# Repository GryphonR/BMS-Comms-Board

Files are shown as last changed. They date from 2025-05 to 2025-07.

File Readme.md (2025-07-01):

# eChook BMS Comunications Master Board
This project is heavily inspired by the [SimpBMS](https://github.com/Tom-evnut/SimpBMS) project by [Tom-evnut](https://github.com/Tom-evnut). The SimpBMS Hardware was never open-sourced, and has become obsolete post-COVID with the demise of the Teensy 3.x development boards.  
This board uses a Teensy 4.1 to mirror, then expand on the functionality of the original SimpBMS board.

While effort has been made to maintain some cross compatibility with the SimpBMS in connector choices and pinouts, this board is **not** a drop in replacement.

## License
This hardware design is released under a non-commercial open hardware licence, is provided **"as is"**, without warranty of any kind, express or implied. See the License.md file for details.

## Features

**ALL UNTESTED**

In addition to an expanded feature set over the SimpBMS, this board offers far more comprehensive circuit protection, most notably offering electrically isolated power and comms for the Battery Module connections, short circuit protection on all off board voltage feeds, so a harness issue does not take down the BMS, and 24v overvoltage protection on all digital and analogue inputs.

IO Overview:  
- 3 CAN Busses (All ESD protected, one Isolated for Battery Module comms).
    - Switchable Terminating Resistor for each bus.
- 2 UART, ESD protected and buffered.
    - One Isolated for Tesla Battery Module Comms.
    - One non-isolated, with selectable voltage levels.
- 1 RS-458/Modbus Interface
- 4 24v safe digital inputs
- 4 Monitored and Overcurrent protected 12v 5A High Side Drivers
- 4 5A Low Side Drivers
- 3 Short Circuit protected 12v outputs
- 4 Short Circuit Protected 5V outputs (One Isolated)
- 2 Analogue Inputs for Current Sensor signals, 24V safe.
- 1 I2C header for 0.91" OLED display.
- 1 SD card slot on the Teensy 4.1 to allow for logging with RTC timestamping.
- Ultra Bright Red error LED
- Warning Buzzer indicating BMS error or blown fuse (On, unless actively turned off by Teensy)

A little more detail:  
- Networks:
    - Electronically isolated communication busses for battery slave module communications.
        - Isolated 5V UART port for Tesla Module Communications (Teensy Serial2)
        - Isolated 600mA 5V supply 
        - Isolated CAN (Teensy CAN1) Connection for (most other) battery modules that communicate over CAN
    - Two non-isolated CAN busses, one exposed on the RJ-45 connector (CAN3), a second exposed on the J5 Auxillary Comms connector (CAN2)
    - One RS-485/MODBUS interface (Teensy Serial8)
    - RJ-45 connector with VICTRON compatible pin out as default, but 'Pick Your Own Pinout' pads on the bottom of the board to allow this to be modified to any application with a bit of soldering.
    - Serial output on J5 (Serial7). Voltage is selectable between 5V and 3.3v by solder jumper on rear of board.
- I/O
    - 4 High Impedence digital inputs, up to 24V.
    - 4 12V High Side Driver outputs, each with voltage, current and temperature monitoring, automatic over temperature, short circuit protection and error state reporting.
    - 4 PWM Capable Low Side Driver outputs with over current/short circuit protection, over temperature protecton. LOW Speed PWM only - testing needed, suspect <2KHz.
- Voltage Supply
    - 5V 500mA Isolated voltage supply for Tesla BMS Boards. Short circuit protected with red fault LED
    - 3 5V 500mA Voltage supplies on J2, J4 and J5, each short circuit protected with red fault LED
    - 3 12v Supplies on J4, Pins 10 and 11 sharing one short circuit protection ciruit, Pin 9 with it's own short circuit protection circuit.
- Warning System
    - Audible warning via a buzzer. This sounds if the onboard fuse blows, or if it is not actively being turned off by the Teensy.
    - Visual warning via 10mA Red LED. This is driven by the Teensy.
    - Heartbeat - Green LED located in cheesy silkscreen image of a heart will blink regularly if the system is healthy.

## Firmware
Due to the swap to a Teensy 4.1, expanded capabilities of the board, and a few pinout changes that go along with both of those, this board is not directly compatible with the SimpBMS code. There is an updated fork of the TeslaBMSV2 firmware adapted for this board here **TODO - link**.

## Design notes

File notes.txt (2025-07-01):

[x] Mosfet drivers - more than 330 gate R

[x] Mosfet - default ON

[x] 5V prot out - 400w TVS?

[x] UART Buffer - voltage switch on wrong input

[ ] advanced output v prot - mosfet right way around?

[x] Terminating Resistors - ensure 1/2W rating.

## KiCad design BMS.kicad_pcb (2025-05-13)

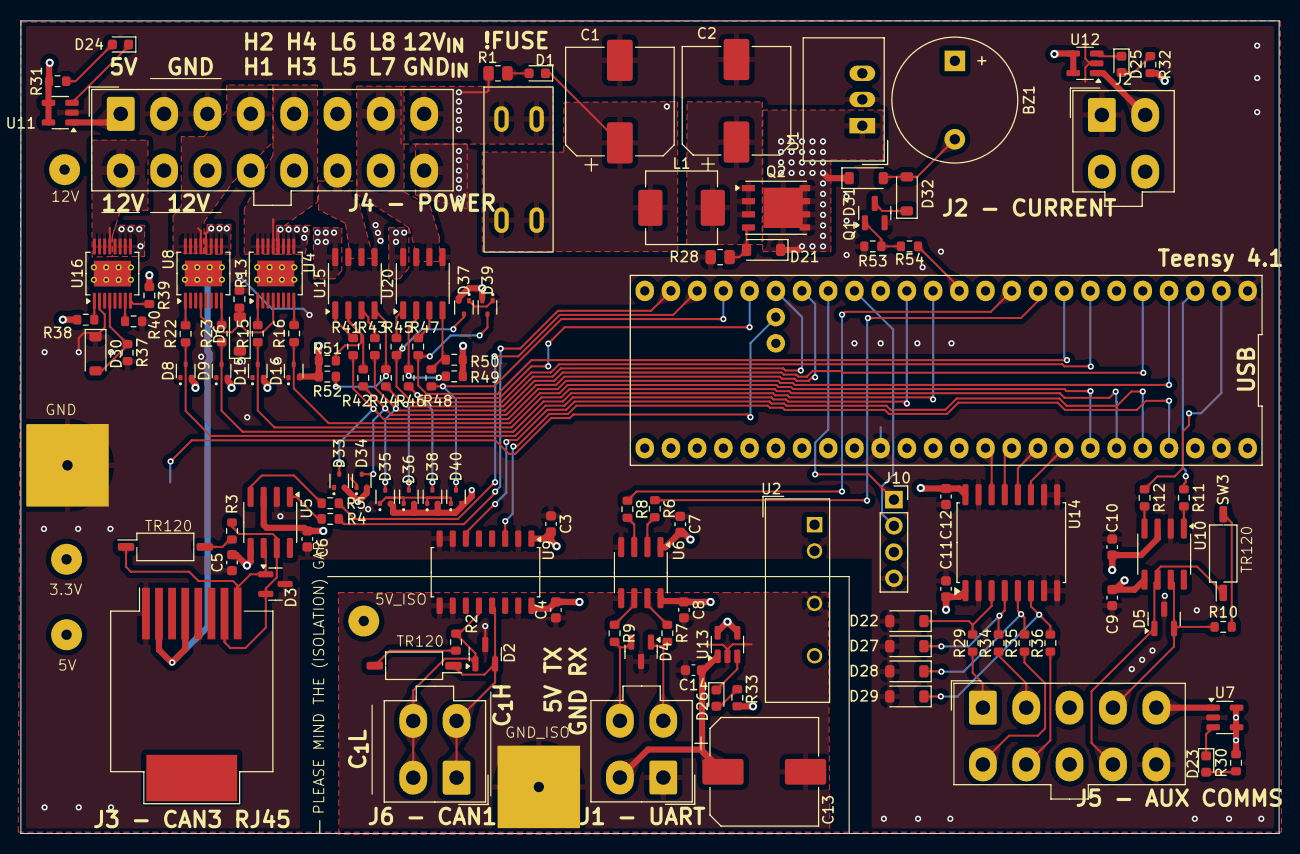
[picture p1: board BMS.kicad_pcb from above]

Board: 4 copper layers, 121.9 x 78.7 mm, 127 parts (1 on the bottom side), 108 nets.

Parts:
BT1: Battery_Cell; BatteryHolder_Keystone_1060_1x2032
BZ1: Buzzer; Buzzer_12x9.5RM7.6
C1, C2, C13: 470uF; CP_Elec_10x10
C3, C4, C5, C6, C7, C8, C9, C10, C11, C12, C14: 1uF; C_0603_1608Metric
D1: LED; LED_0603_1608Metric
D2, D3, D4, D5: PESD1CAN; SOT-23
D6, D30, D31, D32: D; D_SOD-123
D8, D9, D15, D16, D33, D34, D35, D36, D37, D38, D39, D40: BAT54S; SOT-523
D21: 10V; D_SOD-123
D22, D27, D28, D29: 4.7V Zener 500mW; D_SOD-123
D23, D24, D25, D26: LED_RED; LED_0603_1608Metric
F1: Mini Blade Fuse (10A); XFCN XF-508P-B-B
J1, J2, J6: Conn_02x02_Counter_Clockwise; Molex_Mini-Fit_Jr_5566-04A_2x02_P4.20mm_Vertical
J3: RJ45; RJ45_Molex_0855135013_Vertical
J4: Conn_02x08_Top_Bottom; Molex_Mini-Fit_Jr_5566-16A_2x08_P4.20mm_Vertical
J5: Conn_02x05_Top_Bottom; Molex_Mini-Fit_Jr_5566-10A_2x05_P4.20mm_Vertical
J10: OLED; PinSocket_1x04_P2.54mm_Vertical
L1: 1.5uH; L_Changjiang_FXL0618
Q1: BSS138LT1G; SOT-23
Q2: HSBA100P03; PowerPAK_SO-8_Single
R1, R28: 10k; R_0805_2012Metric
R2, R3, R10: 120; R_0603_1608Metric
R4, R5, R6, R7, R8, R9, R11, R12: 330R; R_0603_1608Metric
R13, R29, R34, R35, R36, R37, R53: 4.7k; R_0603_1608Metric
R15, R16, R22, R23, R38, R39: 15k; R_0603_1608Metric
R30, R31, R32, R33: 3.3k; R_0603_1608Metric
R40, R41, R42, R43, R44, R45, R46, R47, R48: 1k; R_0603_1608Metric
R49, R50, R51, R52: 47k; R_0603_1608Metric
R54: 330; R_0603_1608Metric
SW1, SW2, SW3: SW_DIP_x01; SW_DIP_SPSTx01_Slide_Copal_CHS-01B_W7.62mm_P1.27mm
TP1, TP4: TestPoint; Clip_TP
TP2, TP3, TP5, TP6: TestPoint; STD_TP
U1: K7805M-1000R3; Converter_DCDC_TRACO_TSR-1_THT
U2: B0505S-3WR2; Converter_DCDC_TRACO_TBA1-xxxxE_Single_THT
U3: Teensy4.1; Teensy_4.1_RTC
U4, U8, U16: VND7050AJTR; PowerSSO-16-1EP_3.9x4.9mm_P0.5mm_EP2.5x3.61mm_ThermalVias
U5, U10: TJA1051T/3/1J; SOIC-8_3.9x4.9mm_P1.27mm
U6: ISO7331C; SOIC-8_3.9x4.9mm_P1.27mm
U7, U11, U12, U13: TPS2051CDBV; SOT-23-5
U9: ISO1050DWR; SOP-16_4.55x10.3mm_P1.27mm
U14: CA-IS3740; SOIC-16W_7.5x10.3mm_P1.27mm
U15, U20: VNLD5090TR-E; SO-8_3.9x4.9mm_P1.27mm

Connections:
+3.3V: C3.2, C5.2, C7.2, C9.2, C12.2, D8.2 (K), D9.2 (K), D15.2 (K), D16.2 (K), D33.2 (K), D34.2 (K), D35.2 (K), D36.2 (K), D37.2 (K), D38.2 (K), D39.2 (K), D40.2 (K), J10.3, R49.2, R50.2, R51.2, R52.2, TP6.1, U3.15 (3V3), U3.46 (3V3), U3.50 (3.3V), U5.5 (Vref), U6.1 (VCC1), U9.1 (VCC1), U10.5 (Vref), U14.16 (VDD_{B})
+5V: C6.2, C10.2, C11.1, R30.2, R31.2, R32.2, R38.1, R39.1, TP5.1, U1.3 (Vout), U2.1 (+Vin), U3.48 (VIN), U5.3 (VDD), U7.4 (EN), U7.5 (IN), U10.3 (VDD), U11.4 (EN), U11.5 (IN), U12.4 (EN), U12.5 (IN), U14.1 (VDD_{A})
+5V_ISO: C4.2, C8.2, R33.2, TP3.1, U2.6 (+Vout), U6.8 (VCC2), U9.16 (VCC2), U13.4 (EN), U13.5 (IN)
+12V: D21.1 (K), D31.1 (K), J3.2, J3.4, Q2.5 (D), TP2.1, U1.1 (Vin), U4.17 (V_{cc}), U8.17 (V_{cc}), U16.17 (V_{cc})
/12V_INPUT: BZ1.1 (+), F1.1, J4.8, R1.2
/12V_Out_Bank1: J4.9, U16.13 (Output_0), U16.14 (Output_0), U16.15 (Output_0), U16.16 (Output_0)
/12V_Out_Bank2: J4.10, J4.11, U16.9 (Output_1), U16.10 (Output_1), U16.11 (Output_1), U16.12 (Output_1)
/12V_Output_Protection/Driver_Gnd: D30.2 (A), R37.1, U16.4 (GND)
/Buzzer_-ve: D32.1 (K), Q1.3 (D)
/Buzzer_Logic: R54.2, U3.12 (10_CS_MQSR)
/CAN1_HIGH_ISO: D2.2 (A2), J6.1, J6.3, SW1.1, U9.13 (CANH)
/CAN1_LOW_ISO: D2.1 (A1), J6.2, J6.4, R2.1, U9.12 (CANL)
/CAN1_RX: U3.45 (23_A9_CRX1_MCLK1), U9.3 (RXD)
/CAN1_TX: U3.44 (22_A8_CTX1), U9.6 (TXD)
/CAN2_HIGH: D5.2 (A2), J5.4, R10.1, U10.7 (CANH)
/CAN2_LOW: D5.1 (A1), J5.9, SW3.1, U10.6 (CANL)
/CAN2_RX: R12.1, U3.2 (0_RX1_CRX2_CS1)
/CAN2_TX: R11.1, U3.3 (1_TX1_CTX2_MISO1)
/CAN3_HIGH: D3.2 (A2), J3.7, R3.1, U5.7 (CANH)
/CAN3_LOW: D3.1 (A1), J3.8, SW2.1, U5.6 (CANL)
/CAN3_RX: R5.1, U3.22 (30_CRX3)
/CAN3_TX: R4.1, U3.23 (31_CTX3)
/High Side Drivers/Driver_Gnd: D6.2 (A), R13.1, U4.4 (GND), U8.4 (GND)
/In_1: J5.1, R29.1
/In_2: J5.2, R34.1
/In_3: J5.6, R35.1
/In_4: J5.7, R36.1
/Logic_IN_1: U3.38 (16_A2_RX4_SCL1), U14.14 (Out_{1})
/Logic_IN_2: U3.39 (17_A3_TX4_SDA1), U14.13 (Out_{2})
/Logic_IN_3: U3.40 (18_A4_SDA), U14.12 (Out_{3})
/Logic_IN_4: U3.41 (19_A5_SCL), U14.11 (Out_{4})
/OUT1_HSD_LOGIC: D9.3 (COM), R23.1, U3.13 (11_MOSI_CTX1)
/OUT1_HSD_PWR: J4.12, U8.9 (Output_1), U8.10 (Output_1), U8.11 (Output_1), U8.12 (Output_1)
/OUT2_HSD_LOGIC: D8.3 (COM), R22.1, U3.14 (12_MISO_MQSL)
/OUT2_HSD_PWR: J4.4, U8.13 (Output_0), U8.14 (Output_0), U8.15 (Output_0), U8.16 (Output_0)
/OUT3_HSD_LOGIC: D16.3 (COM), R16.1, U3.42 (20_A6_TX5_LRCLK1)
/OUT3_HSD_PWR: J4.13, U4.9 (Output_1), U4.10 (Output_1), U4.11 (Output_1), U4.12 (Output_1)
/OUT4_HSD_LOGIC: D15.3 (COM), R15.1, U3.43 (21_A7_RX5_BCLK1)
/OUT4_HSD_PWR: J4.5, U4.13 (Output_0), U4.14 (Output_0), U4.15 (Output_0), U4.16 (Output_0)
/OUT5_LSD_LOGIC: D33.3 (COM), R41.1, U3.4 (2_OUT2)
/OUT5_LSD_PWR: J4.14, U15.6 (Drain_{2})
/OUT5_LSD_Status: D34.3 (COM), R42.1, U3.18 (26_A12_MOSI1)
/OUT6_LSD_LOGIC: D35.3 (COM), R43.1, U3.5 (3_LRCLK2)
/OUT6_LSD_PWR: J4.6, U15.8 (Drain_{1})
/OUT6_LSD_Status: D36.3 (COM), R44.1, U3.19 (27_A13_SCK1)
/OUT7_LSD_LOGIC: D37.3 (COM), R45.1, U3.7 (5_IN2)
/OUT7_LSD_PWR: J4.7, U20.6 (Drain_{2})
/OUT7_LSD_Status: D38.3 (COM), R46.1, U3.20 (28_RX7)
/OUT8_LSD_LOGIC: D39.3 (COM), R47.1, U3.8 (6_OUT1D)
/OUT8_LSD_PWR: J4.15, U20.8 (Drain_{1})
/OUT8_LSD_Status: D40.3 (COM), R48.1, U3.21 (29_TX7)
/Overcurrent_Protection1/V_{OUT}: J4.1, U11.1 (OUT)
/Overcurrent_Protection2/V_{OUT}: J2.2, U12.1 (OUT)
/Overcurrent_Protection3/V_{OUT}: C13.1, C14.1, J1.2, U13.1 (OUT)
/Overcurrent_Protection/V_{OUT}: J5.5, U7.1 (OUT)
/RTC_BATT_+: BT1.1 (+), U3.49 (V_BATT_RTC)
/SERIAL_RX: R6.1, U3.9 (7_RX2_OUT1A)
/SERIAL_TX: R8.1, U3.10 (8_TX2_IN1)
/UART_RX_ISO: D4.1 (A1), J1.3, R7.2
/UART_TX_ISO: D4.2 (A2), J1.4, R9.2
GND: BT1.2 (-), C1.2, C2.2, C3.1, C5.1, C6.1, C7.1, C9.1, C10.1, C11.2, C12.1, D3.3 (common), D5.3 (common), D6.1 (K), D8.1 (A), D9.1 (A), D15.1 (A), D16.1 (A), D22.2 (A), D27.2 (A), D28.2 (A), D29.2 (A), D30.1 (K), D33.1 (A), D34.1 (A), D35.1 (A), D36.1 (A), D37.1 (A), D38.1 (A), D39.1 (A), D40.1 (A), J2.1, J3.1, J3.5, J4.2, J4.3, J4.16, J5.10, J10.4, Q1.2 (S), R13.2, R28.1, R37.2, R40.1, R53.2, TP4.1, U1.2 (GND), U2.2 (-Vin), U3.1 (GND), U3.34 (GND), U3.47 (GND), U5.2 (VSS), U6.4 (GND1), U7.2 (GND), U9.2 (GND1), U9.7 (GND1), U9.8 (GND1), U10.2 (VSS), U11.2 (GND), U12.2 (GND), U14.2 (GND_{A}), U14.7 (EN_{A}), U14.8 (GND_{A}), U14.9 (GND_{B}), U14.10 (EN_{B}), U14.15 (GND_{B}), U15.5 (Source_{2}), U15.7 (Source_{1}), U16.2 (~FaultRST), U20.5 (Source_{2}), U20.7 (Source_{1})
GND_ISO: C4.1, C8.1, C13.2, C14.2, D2.3 (common), D4.3 (common), J1.1, TP1.1, U2.4 (-Vout), U6.5 (GND2), U9.9 (GND2), U9.10 (GND2), U9.15 (GND2), U13.2 (GND)
I2C_SCL: J10.2, U3.16 (24_A10_TX6_SCL2)
I2C_SDA: J10.1, U3.17 (25_A11_RX6_SDA2)
unnamed: BZ1.2 (-), D31.2 (A), D32.2 (A)
unnamed: C2.1, L1.2, Q2.1 (S), Q2.2 (S), Q2.3 (S)
unnamed: D1.2 (A), R1.1
unnamed: C1.1, D1.1 (K), F1.2, L1.1
unnamed: D21.2 (A), Q2.4 (G), R28.2
unnamed: D22.1 (K), R29.2, U14.3 (In_{1})
unnamed: D23.2 (A), R30.1
unnamed: D23.1 (K), U7.3 (~FLT)
unnamed: D24.2 (A), R31.1
unnamed: D24.1 (K), U11.3 (~FLT)
unnamed: D25.2 (A), R32.1
unnamed: D25.1 (K), U12.3 (~FLT)
unnamed: D26.2 (A), R33.1
unnamed: D26.1 (K), U13.3 (~FLT)
unnamed: D27.1 (K), R34.2, U14.4 (In_{2})
unnamed: D28.1 (K), R35.2, U14.5 (In_{3})
unnamed: D29.1 (K), R36.2, U14.6 (In_{4})
unnamed: Q1.1 (G), R53.1, R54.1
unnamed: R2.2, SW1.2
unnamed: R3.2, SW2.2
unnamed: R10.2, SW3.2
unnamed: R15.2, U4.1 (Input_0)
unnamed: R16.2, U4.8 (Input_1)
unnamed: R5.2, U5.4 (RXD)
unnamed: R4.2, U5.1 (TXD)
unnamed: R7.1, U6.7 (INA)
unnamed: R8.2, U6.3 (INB)
unnamed: R6.2, U6.2 (OUTA)
unnamed: R9.1, U6.6 (OUTB)
unnamed: R22.2, U8.1 (Input_0)
unnamed: R23.2, U8.8 (Input_1)
unnamed: R12.2, U10.4 (RXD)
unnamed: R11.2, U10.1 (TXD)
unnamed: R41.2, U15.1 (IN_{1})
unnamed: R43.2, U15.3 (IN_{2})
unnamed: R42.2, R51.1, U15.2 (Status_{1})
unnamed: R44.2, R52.1, U15.4 (Status_{2})
unnamed: R38.2, U16.1 (Input_0)
unnamed: R39.2, U16.8 (Input_1)
unnamed: R40.2, U16.7 (Multisense)
unnamed: R45.2, U20.1 (IN_{1})
unnamed: R47.2, U20.3 (IN_{2})
unnamed: R46.2, R49.1, U20.2 (Status_{1})
unnamed: R48.2, R50.1, U20.4 (Status_{2})

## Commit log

2025-04-19 Added isolated CAN, UART and PWR
    [BMS.kicad_sch]
2025-05-06 Adding BOM Info
    [BMS.kicad_pcb, BMS.kicad_sch, CAN_Transceiver.kicad_sch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]
2025-05-06 Adding Part Numbers
    [BMS.kicad_sch, CAN_Transceiver.kicad_sch]
2025-05-06 Updated Isolated CANTX
    [CAN_Transceiver.kicad_sch, Isolated_CAN_Transceiver.kicad_sch]
2025-05-07 Connectors, high side circuits added, layout progressed
    [4_High_Side_Driver.kicad_sch, 5V_Overcurrent_Protection.kicad_sch, BMS.kicad_pcb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]
2025-05-08 Added LSD, HSD, Improved Layout
    [10A Low Side Driver.kicad_sch, 4 High Current Low Side Drivers.kicad_sch, BMS.kicad_pcb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]
2025-05-12 Added 12v Out Protection, generally completed layout
    [10A Low Side Driver.kicad_sch, 12V_Output_Protection.kicad_sch, 4 High Current Low Side Drivers.kicad_sch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]
2025-05-13 All the diodes, and other layout work
    [12V_Output_Protection.kicad_sch, 4_High_Side_Driver.kicad_sch, 4_Smart_LSD.kicad_sch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]
2025-05-15 Layout, smaller resistors and HB + Error LEDs
    [12V_Output_Protection.kicad_sch, 4_High_Side_Driver.kicad_sch, BMS.kicad_sch]
2025-05-15 Schematic Layout Improvements, Start of RS485 Circuit
    [5V_Overcurrent_Protection.kicad_sch, BMS.kicad_sch]
2025-05-21 Finalised RS485 Circuit, Layout improvemnts, mounting holes, silkscreen...
    [12V_Output_Protection.kicad_sch, 4_High_Side_Driver.kicad_sch, 4_Smart_LSD.kicad_sch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]
2025-05-22 Pinout swapped for PWMable Error LED
    [BMS.kicad_sch]
2025-05-29 Added UART Buffer for Aux Connector Serial
    [4_Smart_LSD.kicad_sch, BMS.kicad_sch, UART_Isolated_Interface.kicad_sch]
2025-06-04 Added hieracical schematic for better 5V_OUT protection
    [5V_OCP_OVP_RPP.kicad_sch, BMS.kicad_sch]
2025-06-11 Fixed network pinouts - no shared pins now
    [BMS.kicad_sch]
2025-06-12 'Fixed' Molex Footprints - 2x8 not genuine molex, 4.2 instead of 5.5 RS
    [BMS.kicad_sch]
2025-06-16 ISOCAN footprint update, zone optimisations
    [Isolated_CAN_Transceiver.kicad_sch]
2025-06-16 Schematic Net Colours
    [4_High_Side_Driver.kicad_sch, BMS.kicad_sch, Isolated_CAN_Transceiver.kicad_sch]
2025-06-16 PCB Improvements - VIAS/Pours UNFINISHED
    [4_High_Side_Driver.kicad_sch, 4_Smart_LSD.kicad_sch, BMS.kicad_sch]
2025-06-18 J5 Bottom Silkscreen, Schematic organise
    [BMS.kicad_sch, CAN_Transceiver.kicad_sch]
2025-06-24 Further Schematic Tidy
2025-07-01 Implemented schematic review suggestions (Notes.txt)
    [5V_Overcurrent_Protection.kicad_sch, BMS.kicad_sch, CAN_Transceiver.kicad_sch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]
2025-07-14 Corrected Can Transceiver Datasheet Link. Updated Kicad to 9.0.3
    [CAN_Transceiver.kicad_sch]
2025-07-14 Added 5V protection capacitors, altered 5V_ISO Output Caps, Corrected RX<>TX for Serial3
    [5V_Overcurrent_Protection.kicad_sch, BMS.kicad_sch, CAN_Transceiver.kicad_sch]
2025-07-15 Added pulldown safety resistors, layout improvements
    [4_High_Side_Driver.kicad_sch, 4_Smart_LSD.kicad_sch, 5V_Overcurrent_Protection.kicad_sch]
2025-07-24 Post Chris Layout Review
    [BMS.kicad_sch]
2025-08-06 Updated RPP Mosfet to 100V device
    [BMS.kicad_sch]
2025-08-06 Placed RPP in front of Pi Filter, to protect electrolytics from RP
    [BMS.kicad_sch]
2025-08-06 added 12v Feed Error LEDs
    [12V_Output_Protection.kicad_sch]
2025-08-06 Error LED defaults to ON, driven OFF by Teensy
    [BMS.kicad_sch]
2025-08-06 Rear Silkscreen labels and Buzzer solder jumper
2025-08-06 Added Silkscreen Labels
    [BMS.kicad_sch]
2025-08-07 Pinout Review Complete, Altenative option for ISO CAN IC added
    [BMS.kicad_sch, Isolated_CAN_Transceiver.kicad_sch, UART_Isolated_Interface.kicad_sch]
